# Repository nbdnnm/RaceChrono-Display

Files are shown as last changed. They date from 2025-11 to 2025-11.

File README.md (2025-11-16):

_You may [buy me a tea](https://buymeacoffee.com/yugene.ka) if you want to thank me. Also, [I can make the device on demand](mailto:yugene.ka@gmail.com)._

# RaceChrono Display

This project describes how to create an external display to show data from [RaceChrono](https://racechrono.com/) suitable for use on a race track or in daily applications.

The total price for the parts is about 50-70$/Euro (depends if you can print the case cheap)

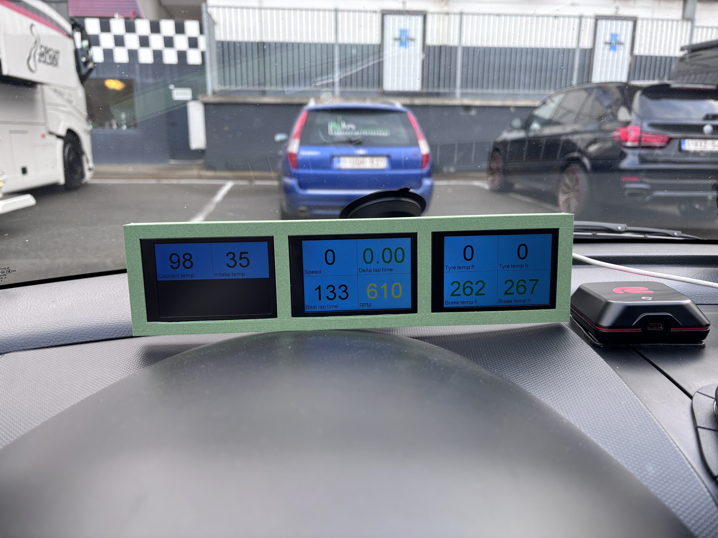
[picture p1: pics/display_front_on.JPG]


## Bill of materials
* ESP32 - the MCU with BLE to manage everything. I used a devkit 30-pin with USB-C, but you can adjust to any kind of ESP32, just reshape the holes and the pins soldering and mapping in the code.
* 3x3.5 inch ST7796 displays, I bought the one by Tenstar Robot from Aliexpress.
* a bit of 24awg wires.
* 12 M2x14mm screws + 12 M2x4mm heat inserts (OD 3.5) to keep everything in place.
* 1 heat insert 1/4-20 length 8mm (OD8mm) to mount on the windshield/dashboard by a GoPro compatible holder.

## Instructions

1. Print the bottom, the top of the box and the cap from the 3d models folder. Use anything up to your taste, or PETG if you don't know what to choose as a material for printing. Print the stick model two times with TPU. They are needed to keep the displays in place by pushing them against the back of the case.

2. Assemble the components as shown below.

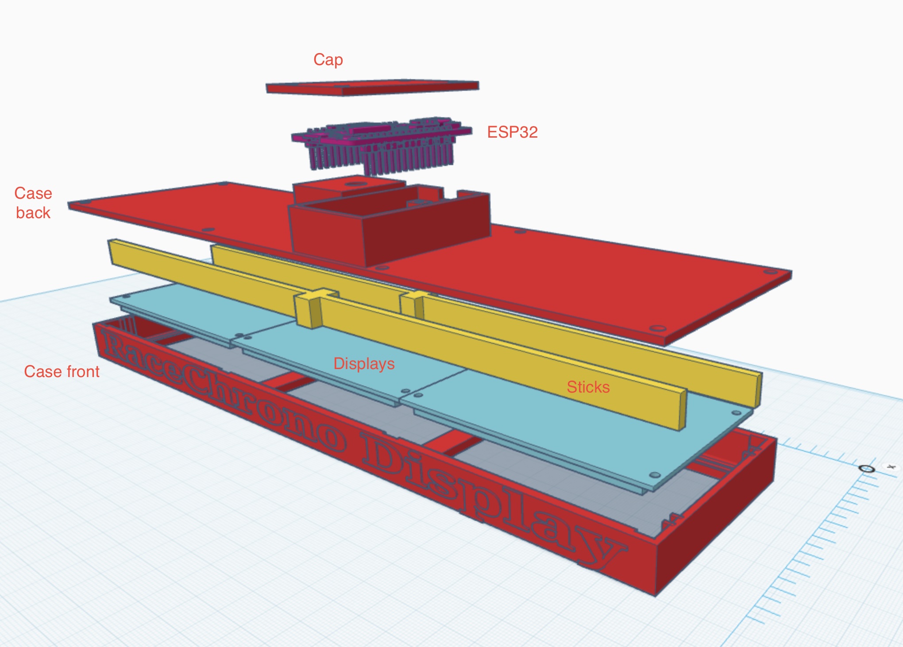
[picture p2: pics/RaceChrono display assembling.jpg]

Place the displays with pins in on the same side (on the right or the left).





Solder the wires to the pins as shown below.

| Display1 | Display2 | Display3 | ESP32 |
|---|---|---|---|
| SDA | SDA | SDA | 23 |
| SCL | SCL | SCL | 18 |
| DC | DC | DC | 17 |
| RST | RST | RST | 16 |
| BL | BL | BL | 15 |
| CS | | | 25 |
| | CS | | 26 |
| | | CS | 27 |

So all the pins of the displays are connected sequentially to each other and then to ESP32, except the CS pins, which are connected to individual ESP32 pins.

The pins mapping can be found in the tft_setup.h file and main.cpp.

Put all the heat inserts and screws.





3. Then download this repo, build and upload it with Arduino IDE with installed libs: TFT_eSPI by Bodmer and NimBLE-Arduino version 1.4.3.

```setRotation``` and ```onScreen``` in the main.cpp are responsible for manipulation the data on the screens. Play with it if you want to adjust it.

```monitors``` array define which data to get from RaceChrono. Put there anything you need and available in https://racechrono.com/support/equations/identifiers

4. Then power it with USB-C in your car and connect to RaceChrono in Settings->Other devices->Add device->RaceChrono DIY->Bluetooth LE->select it and enable Monitor switch->OK

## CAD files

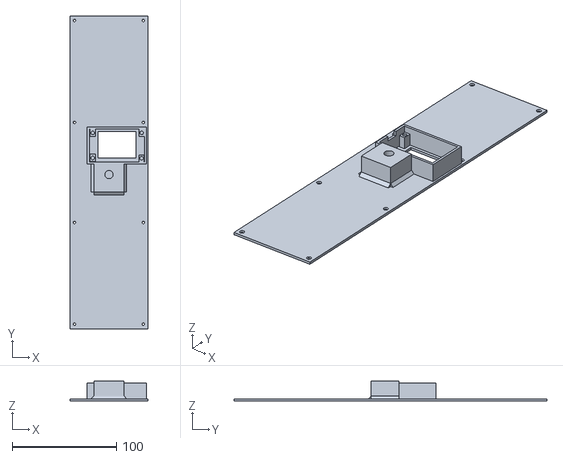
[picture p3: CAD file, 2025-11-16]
3d models/RC display back.stl
75.0 x 300.0 x 19.1

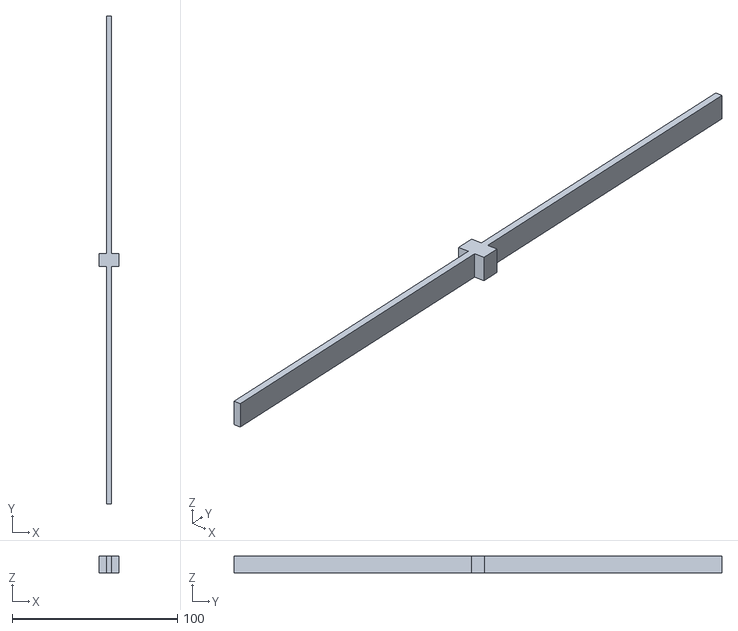
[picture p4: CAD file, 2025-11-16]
3d models/RC display stick.stl
12.2 x 295.6 x 10.2

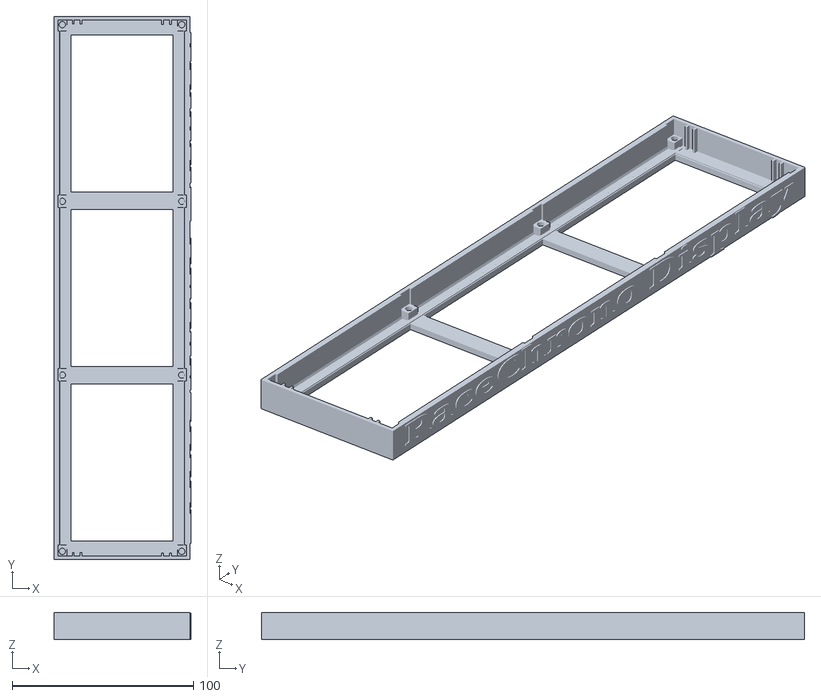
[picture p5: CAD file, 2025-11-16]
3d models/RC display front.stl
75.5 x 300.0 x 15.0

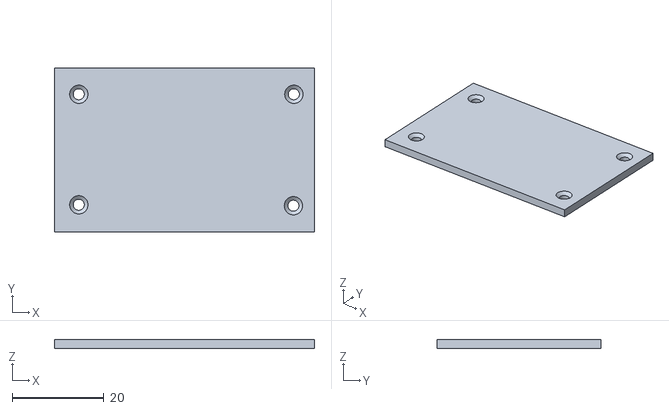
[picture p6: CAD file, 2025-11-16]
3d models/RC display cap.stl
56.7 x 35.7 x 2.00

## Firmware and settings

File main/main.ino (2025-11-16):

#include <Arduino.h>
#include "rcmonitor.h"            // https://github.com/aollin/racechrono-ble-diy-device
#include <TFT_eSPI.h>
#include <cmath>
#include "tft_setup.h"

TFT_eSPI tft = TFT_eSPI();
TFT_eSprite sprite = TFT_eSprite(&tft);
int mainFont = 8;
int secondFont = 4;

//https://racechrono.com/support/equations/identifiers
struct strmon monitors[] = {
    {"Speed", "channel(device(gps), speed)*10.0", 0.36, -1},
    {"Delta lap time", "channel(device(lap), delta_lap_time)*10.0", 0.1, -1},
    {"Best lap time", "channel(device(lap), best_lap_time)*10.0", 0.1, -1},
    {"RPM", "channel(device(obd), rpm)", 1.0, 6800},
    {"Tyre temp fl", "channel(device(wheel), tyre_temp_fl_1)", 1.0, 25},
    {"Tyre temp fr", "channel(device(wheel), tyre_temp_fr_1)", 1.0, 25},
    {"Brake temp fl", "channel(device(canbus), brake_temp_fl)", 1.0, 650},
    {"Brake temp fr", "channel(device(canbus), brake_temp_fr)", 1.0, 650},
    {"Coolant temp", "channel(device(obd), coolant_temp)", 1.0, 98},
    {"Intake temp", "channel(device(obd), intake_temp)", 1.0, -1},
};

#define BUFFSIZE 500
char buff[BUFFSIZE];

std::array<int, 8> convertValues();
void TFT_SET_BL(uint8_t Value);
void onScreen(uint8_t ScreenNumber);

int printAreas[4][2] = {
  {0, 0}, {240, 0}, {0, 160}, {240, 160}
};

#define LeftScreenCS 25
#define CenterScreenCS 26
#define RightScreenCS 27

#define TFT_GREEN_GAIN 0x0400

uint32_t background_color = 0x165d;
uint32_t background_color_backup = 0x165d;

void setup() {
  Serial.begin(115200);

  pinMode(LeftScreenCS,OUTPUT);
  pinMode(CenterScreenCS,OUTPUT);
  pinMode(RightScreenCS,OUTPUT);

  tft.begin();
  tft.setRotation(3);
  tft.fillScreen(TFT_BLACK);
  sprite.createSprite(239, 159);
  
  rcmonitorstart();
  TFT_SET_BL(75);
}


void loop() {
  if (rcmonitor()) {

    bool flash = millis() / 500 % 2; // toggles every 500 ms if the value exceed the alarm threshold

    onScreen(1);
    for (int index = 8; index < 10; index++) {
      int monitorValue = (int)monitorValues[index] * monitorMultipliers[index];

      sprite.setTextSize(1);

      if (monitorValue > 10000) {
        monitorValue = 0;
      }

      if ( monitors[index].alertLevel != -1 && monitorValue >+ monitors[index].alertLevel ) {
        background_color = flash ? TFT_RED : background_color_backup;
      } else {
        background_color = background_color_backup;
      }
      sprite.fillSprite(background_color);

      sprite.setTextDatum(MC_DATUM);// middle center

      sprite.setTextColor(TFT_BLACK, background_color);
      sprite.drawNumber((int)monitorValue, 
                              109, 74, mainFont);// center of 218x148
      sprite.setTextSize(1);
      sprite.setTextDatum(BL_DATUM);
      sprite.drawString(monitors[index].nam, 
                            5, 155, secondFont);

      sprite.pushSprite(printAreas[index-8][0] + 1, 
                            printAreas[index-8][1] + 1);
    }

    onScreen(2);
    for (int index = 0; index < 4; index++) {
      float monitorValue = monitorValues[index] * monitorMultipliers[index];

      sprite.setTextSize(1);

      if (monitorValue > 10000) {
        monitorValue = 0;
      }

      if ( monitors[index].alertLevel != -1 && monitorValue >= monitors[index].alertLevel ) {
        background_color = flash ? TFT_RED : background_color_backup;
      } else {
        background_color = background_color_backup;
      }
      sprite.fillSprite(background_color);

      sprite.setTextDatum(MC_DATUM);// middle center

      if (strcmp(monitors[index].nam, "Delta lap time") == 0) {
        if (monitorValue <= 0) {
          sprite.setTextColor(TFT_GREEN_GAIN, background_color);
        } else {
          sprite.setTextColor(TFT_RED, background_color);
        }
        sprite.drawFloat(monitorValue, 2, 
                              120, 74, mainFont);// center of 218x148
        sprite.setTextColor(TFT_BLACK, background_color);

      } else if (strcmp(monitors[index].nam, "RPM") == 0){
          if (monitorValue >= 4000 && monitorValue < 6800) {
            sprite.setTextColor(TFT_GREEN_GAIN, background_color);
        } else if (monitorValue < 4000) {
          sprite.setTextColor(TFT_YELLOW, background_color);
        }
        sprite.drawNumber((int)monitorValue,
                              120, 74, mainFont);// center of 218x148
        sprite.setTextColor(TFT_BLACK, background_color);

      } else {
        sprite.setTextColor(TFT_BLACK, background_color);
        sprite.drawNumber((int)monitorValue, 
                              120, 74, mainFont);// center of 218x148
      }
      sprite.setTextSize(1);
      sprite.setTextDatum(BL_DATUM);
      sprite.drawString(monitors[index].nam, 
                            5, 155, secondFont);

      sprite.pushSprite(printAreas[index][0] + 1, 
                            printAreas[index][1] + 1);
    }

    onScreen(3);
    for (int index = 4; index < 8; index++) {
      int monitorValue = (int)monitorValues[index] * monitorMultipliers[index];

      sprite.setTextSize(1);

      if (monitorValue > 10000) {
        monitorValue = 0;
      }

      if ( monitors[index].alertLevel != -1 && monitorValue >= monitors[index].alertLevel ) {
        background_color = flash ? TFT_RED : background_color_backup;
      } else {
        background_color = background_color_backup;
      }
      sprite.fillSprite(background_color);

      sprite.setTextDatum(MC_DATUM);// middle center

      if (strcmp(monitors[index].nam, "Brake temp fl") == 0 || strcmp(monitors[index].nam, "Brake temp fr") == 0){
        if (monitorValue >= 200 && monitorValue < 650) {
          sprite.setTextColor(TFT_GREEN_GAIN, background_color);
        } else if (monitorValue < 200) {
          sprite.setTextColor(TFT_YELLOW, background_color);
        }
        sprite.drawNumber((int)monitorValue,
                              109, 74, mainFont);// center of 218x148
        sprite.setTextColor(TFT_BLACK, background_color);

      } else {
        sprite.setTextColor(TFT_BLACK, background_color);
        sprite.drawNumber((int)monitorValue, 
                              109, 74, mainFont);// center of 218x148
      }
      sprite.setTextSize(1);
      sprite.setTextDatum(BL_DATUM);
      sprite.drawString(monitors[index].nam, 
                            5, 155, secondFont);

      sprite.pushSprite(printAreas[index-4][0] + 1, 
                            printAreas[index-4][1] + 1);
    }
  }
  delay(100);
}

void TFT_SET_BL(uint8_t Value) {
  if (Value < 0 || Value > 100) {
    printf("TFT_SET_BL Error \r\n");
  } else {
    analogWrite(TFT_BL, Value * 2.55);
  }
}

void onScreen(uint8_t ScreenNumber) {
  if(ScreenNumber == 0) {
    digitalWrite(LeftScreenCS,0);
    digitalWrite(CenterScreenCS,0);
    digitalWrite(RightScreenCS,0);
  } else if(ScreenNumber == 1) {
    digitalWrite(LeftScreenCS,0);
    digitalWrite(CenterScreenCS,1);
    digitalWrite(RightScreenCS,1);
  } else if (ScreenNumber == 2) {
    digitalWrite(LeftScreenCS,1);
    digitalWrite(CenterScreenCS,0);
    digitalWrite(RightScreenCS,1);
  } else if (ScreenNumber == 3) {
    digitalWrite(LeftScreenCS,1);
    digitalWrite(CenterScreenCS,1);
    digitalWrite(RightScreenCS,0);
  } else {
    Serial.println("Wrong screen number selected");
  }
}

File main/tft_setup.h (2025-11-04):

//                            USER DEFINED SETTINGS
//   Set driver type, fonts to be loaded, pins used and SPI control method etc.
//
//   See the User_Setup_Select.h file if you wish to be able to define multiple
//   setups and then easily select which setup file is used by the compiler.
//
//   If this file is edited correctly then all the library example sketches should
//   run without the need to make any more changes for a particular hardware setup!
//   Note that some sketches are designed for a particular TFT pixel width/height

#define USER_SETUP_ID 0xFFFFFFFF

// Define to disable all #warnings in library (can be put in User_Setup_Select.h)
//#define DISABLE_ALL_LIBRARY_WARNINGS

// ##################################################################################
//
// Section 1. Call up the right driver file and any options for it
//
// ##################################################################################

// Define STM32 to invoke optimised processor support (only for STM32)
//#define STM32

// Defining the STM32 board allows the library to optimise the performance
// for UNO compatible "MCUfriend" style shields
//#define NUCLEO_64_TFT
//#define NUCLEO_144_TFT

// STM32 8-bit parallel only:
// If STN32 Port A or B pins 0-7 are used for 8-bit parallel data bus bits 0-7
// then this will improve rendering performance by a factor of ~8x
//#define STM_PORTA_DATA_BUS
//#define STM_PORTB_DATA_BUS

// Tell the library to use 8-bit parallel mode (otherwise SPI is assumed)
//#define TFT_PARALLEL_8_BIT
//#define TFT_PARALLEL_16_BIT // **** 16-bit parallel ONLY with RP2040 processor ****
 
// Display type -  only define if RPi display
//#define RPI_DISPLAY_TYPE // 20MHz maximum SPI

// Only define one driver, the other ones must be commented out
// #define ILI9341_DRIVER       // Generic driver for common displays
//#define ILI9341_2_DRIVER   // Alternative ILI9341 driver, see https://github.com/Bodmer/TFT_eSPI/issues/1172
//#define ILI9342_DRIVER     // Landscape default orientation variant of ILI9341
//#define ST7735_DRIVER      // Define additional parameters below for this display
//#define ILI9163_DRIVER     // Define additional parameters below for this display
//#define S6D02A1_DRIVER
//#define RPI_ILI9486_DRIVER // 20MHz maximum SPI
//#define HX8357B_DRIVER
//#define HX8357C_DRIVER
//#define HX8357D_DRIVER
//#define ILI9481_DRIVER
//#define ILI9486_DRIVER
//#define ILI9488_DRIVER     // WARNING: Do not connect ILI9488 display SDO to MISO if other devices share the SPI bus (TFT SDO does NOT tristate when CS is high)
//#define ST7789_DRIVER      // Full configuration option, define additional parameters below for this display
//#define ST7789_2_DRIVER    // Minimal configuration option, define additional parameters below for this display
//#define R61581_DRIVER
//#define RM68120_DRIVER     // Untested
//#define RM68140_DRIVER
#define ST7796_DRIVER
//#define SSD1351_DRIVER
//#define SSD1963_480_DRIVER
//#define SSD1963_800_DRIVER
//#define SSD1963_800ALT_DRIVER
//#define ILI9225_DRIVER
//#define GC9A01_DRIVER

// Some displays support SPI reads via the MISO pin, other displays have a single
// bi-directional SDA pin and the library will try to read this via the MOSI line.
// To use the SDA line for reading data from the TFT uncomment the following line:

// #define TFT_SDA_READ      // This option is for ESP32 ONLY, tested with ST7789 and GC9A01 display only

// For ST7735, ST7789 and ILI9341 ONLY, define the colour order IF the blue and red are swapped on your display
// Try ONE option at a time to find the correct colour order for your display

//  #define TFT_RGB_ORDER TFT_RGB  // Colour order Red-Green-Blue
//  #define TFT_RGB_ORDER TFT_BGR  // Colour order Blue-Green-Red

// For M5Stack ESP32 module with integrated ILI9341 display ONLY, remove // in line below

// #define M5STACK

// For ST7789, ST7735, ILI9163 and GC9A01 ONLY, define the pixel width and height in portrait orientation
// #define TFT_WIDTH  80
// #define TFT_WIDTH  128
// #define TFT_WIDTH  172 // ST7789 172 x 320
// #define TFT_WIDTH  240 // ST7789 240 x 240 and 240 x 320
#define TFT_WIDTH 320
// #define TFT_HEIGHT 160
// #define TFT_HEIGHT 128
// #define TFT_HEIGHT 240 // ST7789 240 x 240
// #define TFT_HEIGHT 320 // ST7789 240 x 320
// #define TFT_HEIGHT 240 // GC9A01 240 x 240
#define TFT_HEIGHT 480

// For ST7735 ONLY, define the type of display, originally this was based on the
// colour of the tab on the screen protector film but this is not always true, so try
// out the different options below if the screen does not display graphics correctly,
// e.g. colours wrong, mirror images, or stray pixels at the edges.
// Comment out ALL BUT ONE of these options for a ST7735 display driver, save this
// this User_Setup file, then rebuild and upload the sketch to the board again:

// #define ST7735_INITB
// #define ST7735_GREENTAB
// #define ST7735_GREENTAB2
// #define ST7735_GREENTAB3
// #define ST7735_GREENTAB128    // For 128 x 128 display
// #define ST7735_GREENTAB160x80 // For 160 x 80 display (BGR, inverted, 26 offset)
// #define ST7735_REDTAB
// #define ST7735_BLACKTAB
// #define ST7735_REDTAB160x80   // For 160 x 80 display with 24 pixel offset

// If colours are inverted (white shows as black) then uncomment one of the next
// 2 lines try both options, one of the options should correct the inversion.

// #define TFT_INVERSION_ON
// #define TFT_INVERSION_OFF


// ##################################################################################
//
// Section 2. Define the pins that are used to interface with the display here
//
// ##################################################################################

// If a backlight control signal is available then define the TFT_BL pin in Section 2
// below. The backlight will be turned ON when tft.begin() is called, but the library
// needs to know if the LEDs are ON with the pin HIGH or LOW. If the LEDs are to be
// driven with a PWM signal or turned OFF/ON then this must be handled by the user
// sketch. e.g. with digitalWrite(TFT_BL, LOW);

// #define TFT_BL   32            // LED back-light control pin
// #define TFT_BACKLIGHT_ON HIGH  // Level to turn ON back-light (HIGH or LOW)
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

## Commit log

2025-11-16 added readme with instructions and cleanup
    [RC display back.stl, RC display cap.stl, RC display front.stl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]
2025-11-16 add racechrono add device step in readme
